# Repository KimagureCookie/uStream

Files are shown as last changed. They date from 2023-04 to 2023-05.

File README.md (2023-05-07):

### WIP (I'm working on the software side of things right now!)

A few weeks ago, I wanted to buy a hot air station for some smd rework. While I was searchig for one, I came across a lot of chinese hot air stations which seem to be dirt cheap and also resonably reliable. Howerver the problem is that, these seem to be outdated design and somewhat lack in saftey!
On the other hand the offerings from top players like JBC and Wellers seems to be out of reach for any hobbyist.

I guess these are enough excuses for making my own hot air station. Since I can't make the core components (The Heater and air pump units) I will be working on the controller unit. The heater and pumps can be purchased easily through any online repair parts sellers or even better if you could directly buy from chinese sites like aliexpress. 

I will try to add everything I have cooked so far in the coming days.

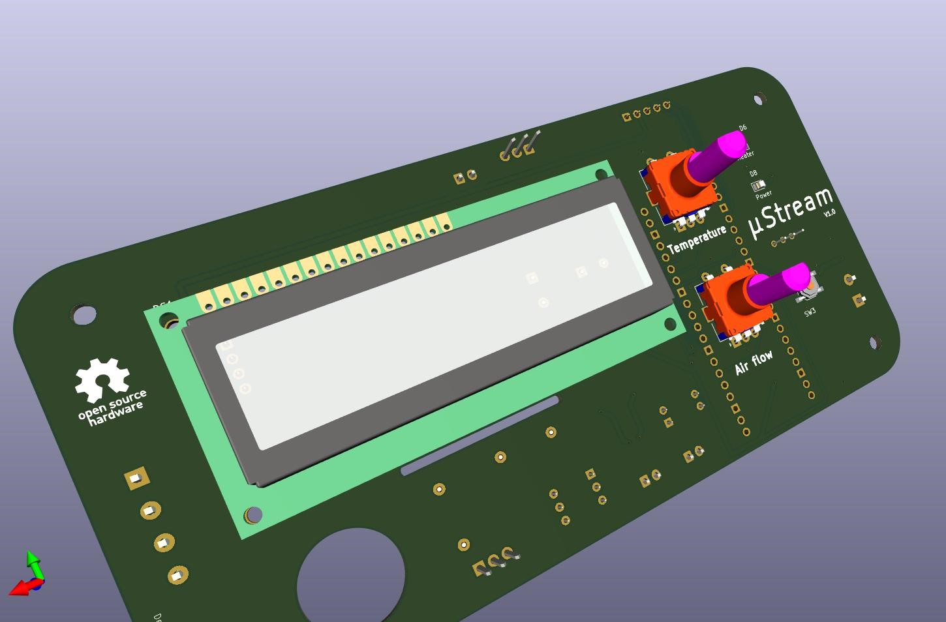
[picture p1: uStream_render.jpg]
micro_stream


Edit: As of now everthing on hardware is tested and corrected in schematics/PCB. The idea of implementing the thermocouple amplifier using an precision op-amp has to be scractched since, I can't figure out the problem with my current setup (glad I implemented the MAX6675 as a backup!).
Although I have run basic software tests, there is still more code to test thoroughly.

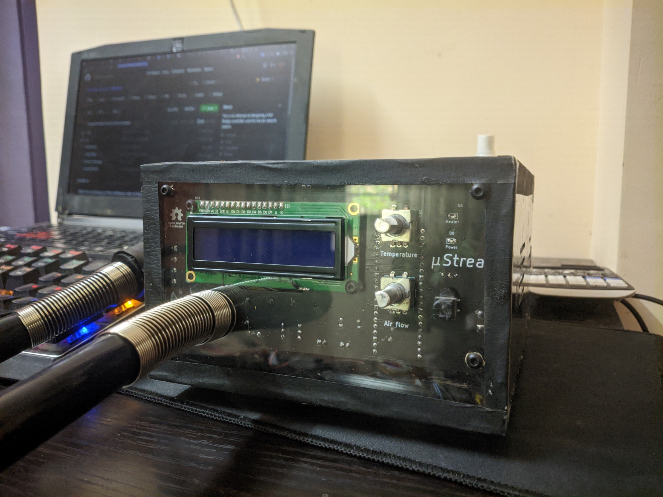
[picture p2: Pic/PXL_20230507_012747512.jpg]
p1


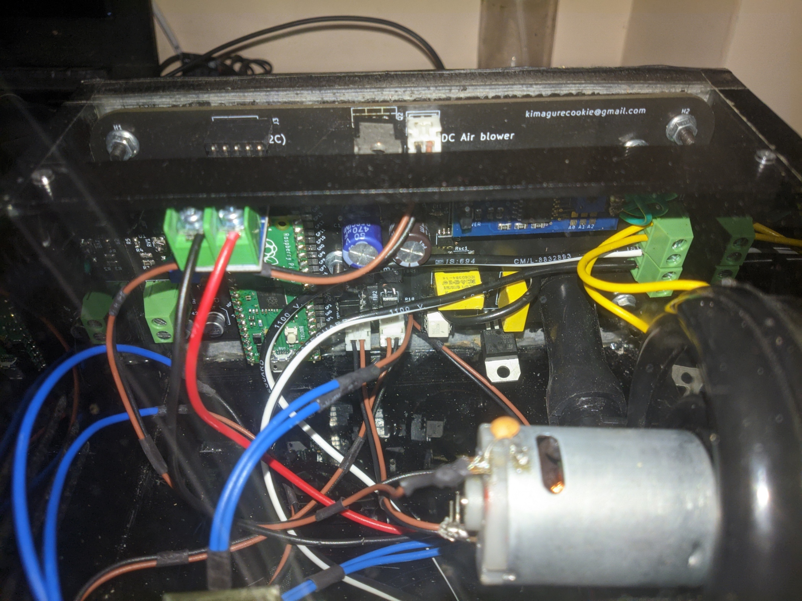
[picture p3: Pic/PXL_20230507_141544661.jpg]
p2


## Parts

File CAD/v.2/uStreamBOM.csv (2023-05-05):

Date: | 5/5/2023 1:10:16 PM
Tool: | Eeschema (6.0.10)
Generator: | C:\Program Files\KiCad\6.0\bin\scripting\plugins/bom_csv_grouped_by_value_with_fp.py
Component Count: | 72
Ref | Qnty | Value | Cmp name | Footprint | Description | Vendor
C1, C5, | 2 | 10u | C | Capacitor_SMD:C_0805_2012Metric_Pad1.18x1.45mm_HandSolder | Unpolarized capacitor
C2, | 1 | 480u | C_Polarized | Capacitor_THT:CP_Radial_D10.0mm_P5.00mm | Polarized capacitor
C3, C7, C11, | 3 | 10u | C_Polarized | Capacitor_SMD:CP_Elec_6.3x5.8 | Polarized capacitor
C4, C6, | 2 | 0.1u | C | Capacitor_SMD:C_0805_2012Metric_Pad1.18x1.45mm_HandSolder | Unpolarized capacitor
C8, | 1 | 220u | C_Polarized | Capacitor_THT:CP_Radial_D10.0mm_P5.00mm | Polarized capacitor
C9, | 1 | 50nf | C | Capacitor_THT:C_Rect_L13.0mm_W6.0mm_P10.00mm_FKS3_FKP3_MKS4 | Unpolarized capacitor
C10, | 1 | 10nf | C | Capacitor_THT:C_Rect_L13.0mm_W6.0mm_P10.00mm_FKS3_FKP3_MKS4 | Unpolarized capacitor
Ct1, | 1 | 260p | C | Capacitor_SMD:C_0805_2012Metric_Pad1.18x1.45mm_HandSolder | Unpolarized capacitor
D1, D4, D7, | 3 | 1N4148 | D | Diode_SMD:D_SOD-123 | Diode
D2, | 1 | 1N5819 | 1N5819 | Diode_SMD:D_SMA_Handsoldering | 40V 1A Schottky Barrier Rectifier Diode, DO-41
D3, | 1 | BZV55C4V7 | BZV55C4V7 | Diode_SMD:D_MiniMELF | 4.7V, 500mW, 5%, Zener diode, MiniMELF
D5, D6, | 2 | LED | LED | LED_SMD:LED_0805_2012Metric_Pad1.15x1.40mm_HandSolder | Light emitting diode
DS1, | 1 | WC1602A | WC1602A | Display:WC1602A | LCD 16x2 Alphanumeric , 8 bit parallel bus, 5V VDD
F1, | 1 | 1A | Fuse |  | Fuse
F2, | 1 | 3A | Fuse |  | Fuse
FBR1, | 1 | ABS10 | ABS10 | Diode_SMD:Diode_Bridge_Vishay_DFS | Miniature Glass Passivated Single-Phase Surface Mount Bridge Rectifiers, 700V Vrms, 0.8A If, ABS SMD package
FBR2, | 1 | RMB4S | RMB4S | Package_TO_SOT_SMD:TO-269AA | Miniature Glass Passivated Single-Phase Surface Mount Bridge Rectifiers, 280V Vrms, 0.5A If, TO-269AA
H1, H2, H3, H4, | 4 | MountingHole | MountingHole | MountingHole:MountingHole_3.2mm_M3 | Mounting Hole without connection
J1, | 1 | Transformer_In | Conn_01x02 | Connector_JST:JST_XH_B2B-XH-A_1x02_P2.50mm_Vertical | Generic connector, single row, 01x02, script generated (kicad-library-utils/schlib/autogen/connector/)
J2, | 1 | Thermocouple junction | Screw_Terminal_01x02 | TerminalBlock_Phoenix:TerminalBlock_Phoenix_MKDS-1,5-2-5.08_1x02_P5.08mm_Horizontal | Generic screw terminal, single row, 01x02, script generated (kicad-library-utils/schlib/autogen/connector/)
J3, | 1 | MAX6675 | Conn_01x05_Male | Connector_PinSocket_2.54mm:PinSocket_1x05_P2.54mm_Vertical | Generic connector, single row, 01x05, script generated (kicad-library-utils/schlib/autogen/connector/)
J4, | 1 | Mains+Heater | Screw_Terminal_01x04 | TerminalBlock_Phoenix:TerminalBlock_Phoenix_MKDS-1,5-4-5.08_1x04_P5.08mm_Horizontal | Generic screw terminal, single row, 01x04, script generated (kicad-library-utils/schlib/autogen/connector/)
J5, | 1 | Air Blower | Conn_01x02 | Connector_JST:JST_XH_B2B-XH-A_1x02_P2.50mm_Vertical | Generic connector, single row, 01x02, script generated (kicad-library-utils/schlib/autogen/connector/)
L1, | 1 | 68u | L | Inductor_SMD:L_Sunlord_SWPA80xxS | Inductor
Q1, | 1 | BTA16-600B | BTA16-600B | Package_TO_SOT_THT:TO-220-3_Vertical | 16A RMS, 600V Off-State Voltage, 50mA Sensitivity, Insulated, Triac, TO-220
Q2, | 1 | STP55NF06 | IRF540N | Package_TO_SOT_THT:TO-220-3_Vertical | 33A Id, 100V Vds, HEXFET N-Channel MOSFET, TO-220
R1, | 1 | 47k | R | Resistor_SMD:R_0805_2012Metric_Pad1.20x1.40mm_HandSolder | Resistor
R2, | 1 | 6.8k | R | Resistor_SMD:R_0805_2012Metric_Pad1.20x1.40mm_HandSolder | Resistor
R3, | 1 | 110 | R | Resistor_SMD:R_0805_2012Metric_Pad1.20x1.40mm_HandSolder | Resistor
R4, | 1 | 102k | R | Resistor_SMD:R_0805_2012Metric_Pad1.20x1.40mm_HandSolder | Resistor
R5, R16, | 2 | 51 | R | Resistor_SMD:R_0805_2012Metric_Pad1.20x1.40mm_HandSolder | Resistor
R6, R21, | 2 | 1k | R | Resistor_SMD:R_0805_2012Metric_Pad1.20x1.40mm_HandSolder | Resistor
R7, | 1 | 2k | R | Resistor_SMD:R_0805_2012Metric_Pad1.20x1.40mm_HandSolder | Resistor
R8, | 1 | 43k | R | Resistor_SMD:R_0805_2012Metric_Pad1.20x1.40mm_HandSolder | Resistor
R9, | 1 | 2.4k | R | Resistor_SMD:R_0805_2012Metric_Pad1.20x1.40mm_HandSolder | Resistor
R10, | 1 | 1.5k | R | Resistor_SMD:R_0805_2012Metric_Pad1.20x1.40mm_HandSolder | Resistor
R11, | 1 | 9.1k | R | Resistor_SMD:R_0805_2012Metric_Pad1.20x1.40mm_HandSolder | Resistor
R12, R13, R14, R15, R22, | 5 | 10k | R | Resistor_SMD:R_0805_2012Metric_Pad1.20x1.40mm_HandSolder | Resistor
R17, | 1 | 510 | R | Resistor_SMD:R_0805_2012Metric_Pad1.20x1.40mm_HandSolder | Resistor
R18, | 1 | 360 | R | Resistor_SMD:R_1206_3216Metric_Pad1.30x1.75mm_HandSolder | Resistor
R19, | 1 | 680 | R | Resistor_SMD:R_1206_3216Metric_Pad1.30x1.75mm_HandSolder | Resistor
R20, | 1 | 360 | R | Resistor_SMD:R_0805_2012Metric_Pad1.20x1.40mm_HandSolder | Resistor
R23, | 1 | 39 | R | Resistor_SMD:R_1206_3216Metric_Pad1.30x1.75mm_HandSolder | Resistor
Rsc1, | 1 | 0.3 | R | Resistor_SMD:R_2512_6332Metric_Pad1.40x3.35mm_HandSolder | Resistor
RV1, | 1 | 100 | R_Potentiometer | Potentiometer_SMD:Potentiometer_Bourns_TC33X_Vertical | Potentiometer
RV2, | 1 | 20k | R_Potentiometer | Potentiometer_THT:Potentiometer_Bourns_3296W_Vertical | Potentiometer
SW1, | 1 | Heater Encoder | RotaryEncoder_Switch | Rotary_Encoder:RotaryEncoder_Alps_EC11E-Switch_Vertical_H20mm | Rotary encoder, dual channel, incremental quadrate outputs, with switch
SW2, | 1 | Control for Air blower | RotaryEncoder_Switch | Rotary_Encoder:RotaryEncoder_Alps_EC11E-Switch_Vertical_H20mm | Rotary encoder, dual channel, incremental quadrate outputs, with switch
SW3, | 1 | SW_SPST | SW_SPST | Button_Switch_SMD:SW_SPST_TL3342 | Single Pole Single Throw (SPST) switch
SW_REED1, | 1 | SW_Reed | SW_Reed | Connector_JST:JST_XH_B2B-XH-A_1x02_P2.50mm_Vertical | reed switch
U1, | 1 | OP07 | OP07 | Package_SO:SOIC-8_3.9x4.9mm_P1.27mm | Single Ultra-Low Offset Voltage Operational Amplifier, DIP-8/SOIC-8
U2, | 1 | MC34063AD | MC34063AD | Package_SO:SOIC-8_3.9x4.9mm_P1.27mm | 1.5A, step-up/down/inverting switching regulator, 3-40V Vin, 100kHz, SO-8
U3, | 1 | PC817 | PC817 | Package_DIP:DIP-4_W7.62mm | DC Optocoupler, Vce 35V, CTR 50-300%, DIP-4
U4, | 1 | EA_T123X-I2C | EA_T123X-I2C | Connector_PinSocket_2.54mm:PinSocket_1x04_P2.54mm_Vertical | 3 Lines, 12 character alpha numeric LCD, transreflective STN and FSTN Gray, I2C, single or dual power
U5, | 1 | Pico | Pico | raspberry pi:RPi_Pico_SMD_TH
U6, | 1 | MOC3022M | MOC3022M | Package_DIP:DIP-6_W7.62mm | Random Phase Opto-Triac, Vdrm 400V, Ift 10mA, DIP6

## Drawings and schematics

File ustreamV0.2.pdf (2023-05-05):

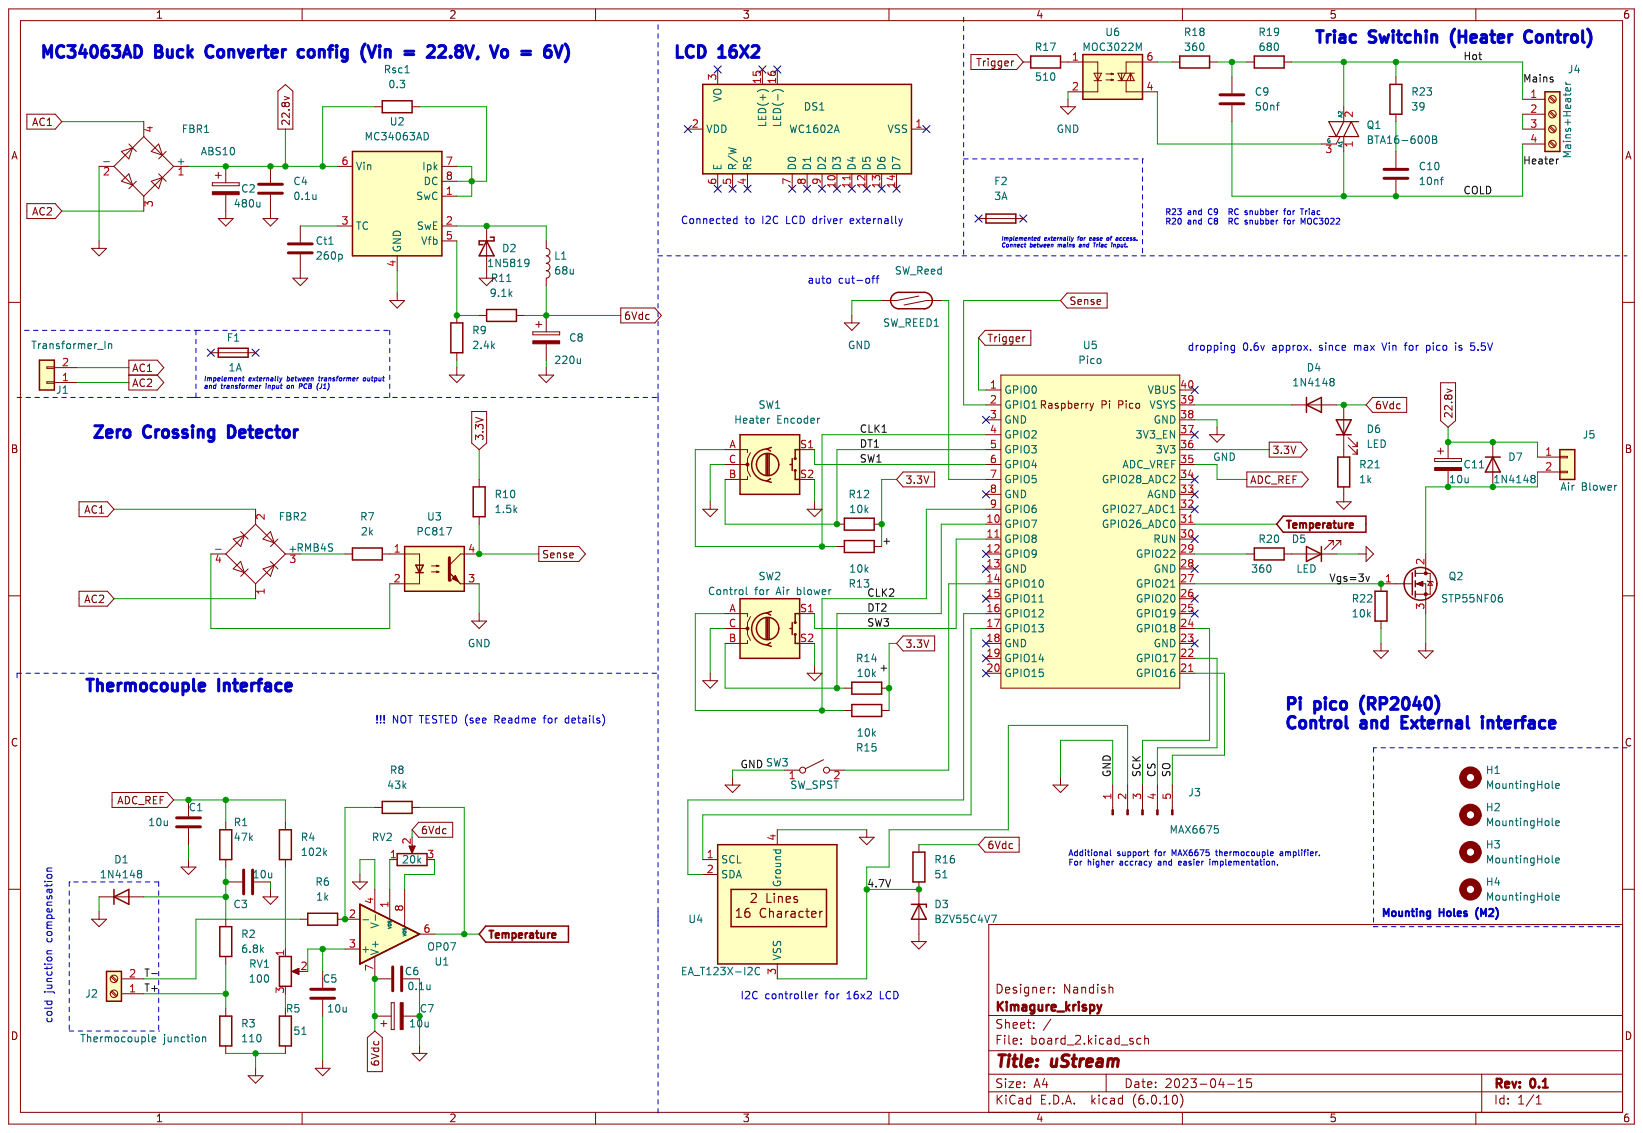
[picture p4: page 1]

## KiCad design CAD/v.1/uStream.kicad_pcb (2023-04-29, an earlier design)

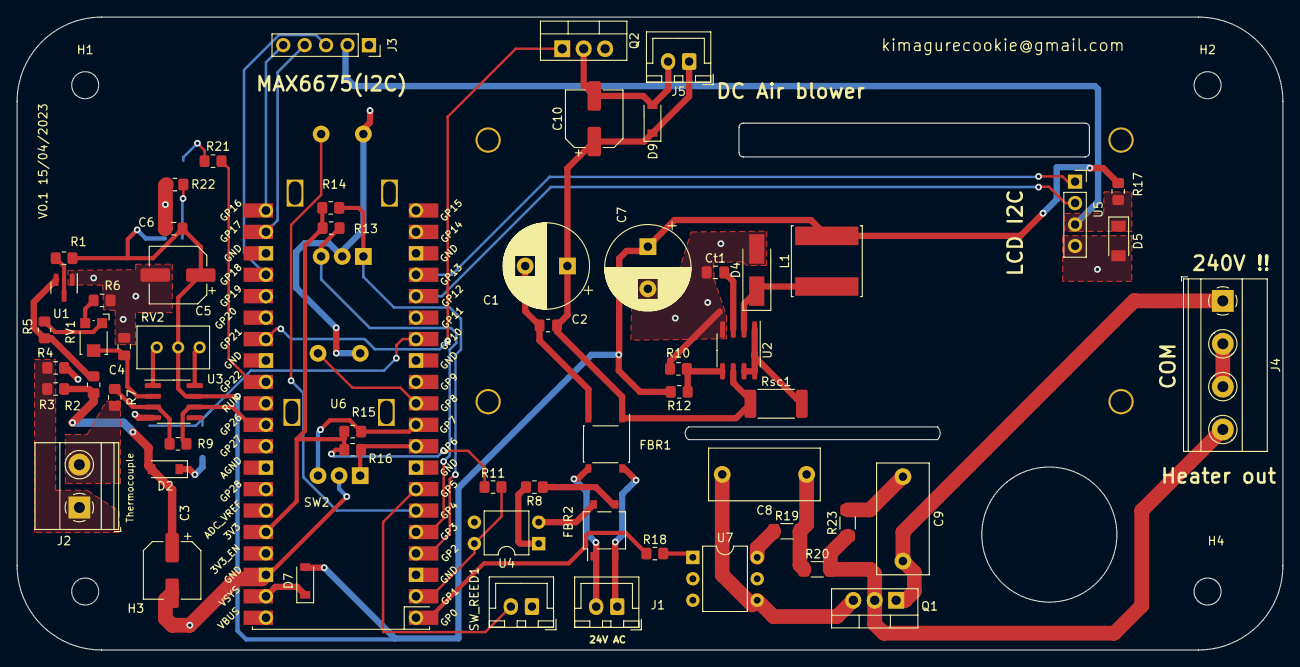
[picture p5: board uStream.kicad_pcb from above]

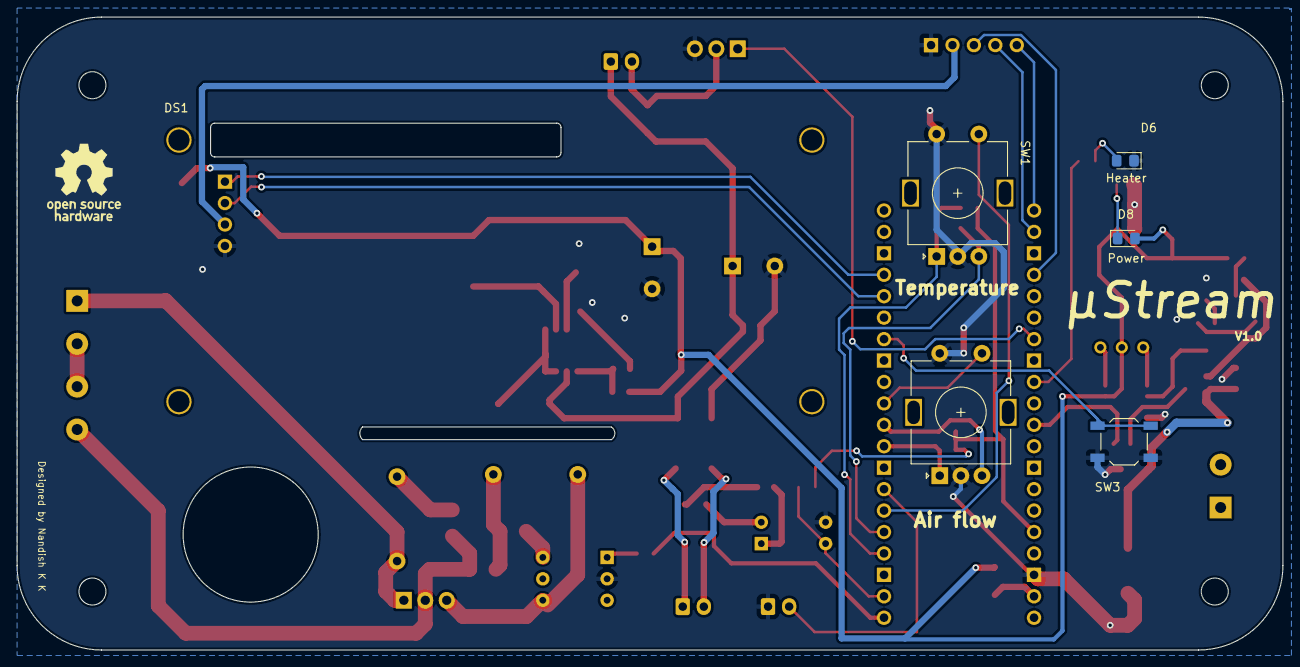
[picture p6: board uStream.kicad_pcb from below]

Board: 2 copper layers, 150.0 x 75.0 mm, 71 parts (7 on the bottom side), 55 nets.

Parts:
C1: 480u; CP_Radial_D10.0mm_P5.00mm
C2, C6: 0.1u; C_0805_2012Metric_Pad1.18x1.45mm_HandSolder
C3, C5, C10: 10u; CP_Elec_6.3x5.8
C4: 10u; C_0805_2012Metric_Pad1.18x1.45mm_HandSolder
C7: 220u; CP_Radial_D10.0mm_P5.00mm
C8: 50nf; C_Rect_L13.0mm_W6.0mm_P10.00mm_FKS3_FKP3_MKS4
C9: 10nf; C_Rect_L13.0mm_W6.0mm_P10.00mm_FKS3_FKP3_MKS4
Ct1: 260p; C_0805_2012Metric_Pad1.18x1.45mm_HandSolder
D2, D7, D9: 1N4148; D_SOD-123
D4: 1N5819; D_SMA_Handsoldering
D5: BZV55C4V7; D_MiniMELF
D6, D8: LED; LED_0805_2012Metric_Pad1.15x1.40mm_HandSolder
DS1: WC1602A
FBR1: ABS10; Diode_Bridge_Diotec_ABS
FBR2: RMB4S; TO-269AA
G: LOGO
H1, H2, H3, H4: MountingHole_3.2mm_M3
J1: Transformer_In; JST_XH_B2B-XH-A_1x02_P2.50mm_Vertical
J2: Thermocouple junction; TerminalBlock_Phoenix_MKDS-1,5-2-5.08_1x02_P5.08mm_Horizont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
J3: MAX6675; PinSocket_1x05_P2.54mm_Vertical
J4: Mains+Heater; TerminalBlock_Phoenix_MKDS-1,5-4-5.08_1x04_P5.08mm_Horizont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
J5: Air Blower; JST_XH_B2B-XH-A_1x02_P2.50mm_Vertical
L1: 68u; L_Sunlord_SWPA80xxS
Q1: BTA16-600B; TO-220-3_Vertical
Q2: STP55NF06; TO-220-3_Vertical
R1, R7, R22: 1k; R_0805_2012Metric_Pad1.20x1.40mm_HandSolder
R2: 47k; R_0805_2012Metric_Pad1.20x1.40mm_HandSolder
R3: 6.8k; R_0805_2012Metric_Pad1.20x1.40mm_HandSolder
R4: 110; R_0805_2012Metric_Pad1.20x1.40mm_HandSolder
R5: 102k; R_0805_2012Metric_Pad1.20x1.40mm_HandSolder
R6: 50; R_0805_2012Metric_Pad1.20x1.40mm_HandSolder
R8: 2k; R_0805_2012Metric_Pad1.20x1.40mm_HandSolder
R9: 43k; R_0805_2012Metric_Pad1.20x1.40mm_HandSolder
R10: 2.4k; R_0805_2012Metric_Pad1.20x1.40mm_HandSolder
R11: 1.5k; R_0805_2012Metric_Pad1.20x1.40mm_HandSolder
R12: 9.1k; R_0805_2012Metric_Pad1.20x1.40mm_HandSolder
R13, R14, R15, R16: 10k; R_0805_2012Metric_Pad1.20x1.40mm_HandSolder
R17: 51; R_0805_2012Metric_Pad1.20x1.40mm_HandSolder
R18: 510; R_0805_2012Metric_Pad1.20x1.40mm_HandSolder
R19: 360; R_1206_3216Metric_Pad1.30x1.75mm_HandSolder
R20: 680; R_1206_3216Metric_Pad1.30x1.75mm_HandSolder
R21: 360; R_0805_2012Metric_Pad1.20x1.40mm_HandSolder
R23: 39; R_1206_3216Metric_Pad1.30x1.75mm_HandSolder
RV1: 100; Potentiometer_Bourns_TC33X_Vertical
RV2: 20k; Potentiometer_Bourns_3296W_Vertical
Rsc1: 0.3; R_2512_6332Metric_Pad1.40x3.35mm_HandSolder
SW1: Heater Encoder; RotaryEncoder_Alps_EC11E-Switch_Vertical_H20mm
SW2: Control for Air blower; RotaryEncoder_Alps_EC11E-Switch_Vertical_H20mm
SW3: SW_SPST; SW_SPST_TL3342
SW_REED1: SW_Reed; JST_XH_B2B-XH-A_1x02_P2.50mm_Vertical
U1: TL431DBZ; SOT-23
U2: MC34063AD; SOIC-8_3.9x4.9mm_P1.27mm
U3: OP07; SOIC-8_3.9x4.9mm_P1.27mm
U4: PC817; DIP-4_W7.62mm
U5: EA_T123X-I2C; PinSocket_1x04_P2.54mm_Vertical
U6: Pico; RPi_Pico_SMD_TH
U7: MOC3022M; DIP-6_W7.62mm

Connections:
3.3V: R11.1, R13.2, R14.2, R15.2, R16.2, U6.36 (3V3)
6Vdc: C5.1, C6.2, C7.1, D7.2 (A), D8.2 (A), L1.2, R1.2, R12.2, R17.1, RV2.2, U3.7 (V+)
22.8v: C1.1, C2.2, C10.1, D9.1 (K), FBR1.1 (+), J5.1, Rsc1.1, U2.6 (Vin)
/4.7V: D5.1 (K), J3.2, R17.2, U5.3 (VSS)
/CLK1: R14.1, SW1.A, U6.4 (GPIO2)
/CLK2: R16.1, SW2.A, U6.9 (GPIO6)
/COLD: C9.2, J4.1, Q1.1 (A1)
/CS: J3.4, U6.22 (GPIO17)
/DT1: R13.1, SW1.B, U6.5 (GPIO3)
/DT2: R15.1, SW2.B, U6.10 (GPIO7)
/Hot: J4.4, Q1.2 (A2), R20.2, R23.1
/SCK: J3.3, U6.24 (GPIO18)
/SO: J3.5, U6.21 (GPIO16)
/SW1: SW1.S1, U6.6 (GPIO4)
/SW3: SW2.S1, U6.11 (GPIO8)
/T+: J2.1, R3.1, R4.2
/T-: J2.2, R7.2
/Vgs=3v: Q2.1 (G), U6.27 (GPIO21)
AC1: FBR1.4, FBR2.2, J1.1
AC2: FBR1.3, FBR2.1, J1.2
GND: C1.2, C2.1, C3.2, C4.2, C5.2, C6.1, C7.2, Ct1.1, D2.1 (K), D4.2 (A), D5.2 (A), D6.1 (K), FBR1.2 (-), J3.1, Q2.3 (S), R4.1, R6.1, R10.2, R22.2, SW1.C, SW1.S2, SW2.C, SW2.S2, SW3.1 (A), SW_REED1.1, U1.1 (K), U2.4 (GND), U3.4 (V-), U4.3, U5.4 (Ground), U6.38 (GND), U7.2
unnamed: C3.1, D2.2 (A), R2.1, R3.2
unnamed: C4.1, RV1.2, U3.2 (-)
unnamed: C8.1, R19.2, R20.1
unnamed: C8.2, Q1.3 (G), U7.4
unnamed: C9.1, R23.2
unnamed: C10.2, D9.2 (A), J5.2, Q2.2 (D)
unnamed: Ct1.2, U2.3 (TC)
unnamed: D4.1 (K), L1.1, U2.2 (SwE)
unnamed: D6.2 (A), R21.2
unnamed: D7.1 (K), U6.39 (VSYS)
unnamed: D8.1 (K), R22.1
unnamed: FBR2.3 (+), R8.1
unnamed: FBR2.4 (-), U4.2
unnamed: J4.2, J4.3
unnamed: R1.1, U1.3 (A)
unnamed: R2.2, R5.1, U1.2 (REF)
unnamed: R5.2, RV1.1
unnamed: R6.2, RV1.3
unnamed: R7.1, R9.2, U3.3 (+)
unnamed: R8.2, U4.1
unnamed: R10.1, R12.1, U2.5 (Vfb)
unnamed: R18.2, U7.1
unnamed: R19.1, U7.6
unnamed: R21.1, U6.29 (GPIO22)
unnamed: RV2.1, U3.8 (VOS)
unnamed: RV2.3, U3.1 (VOS)
unnamed: Rsc1.2, U2.1 (SwC), U2.7 (Ipk), U2.8 (DC)
unnamed: SW3.2 (B), U6.14 (GPIO10)
unnamed: SW_REED1.2, U6.7 (GPIO5)
unnamed: U5.1 (SCL), U6.17 (GPIO13)
unnamed: U5.2 (SDA), U6.16 (GPIO12)
Sense: R11.2, U4.4, U6.2 (GPIO1)
Temperature: R9.1, U3.6, U6.31 (GPIO26_ADC0)
Trigger: R18.1, U6.1 (GPIO0)

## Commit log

2023-04-29 CAD files added
    [uStream.kicad_pcb, uStream.kicad_sch, uStream_BOM.csv]
2023-05-06 schematic and pcb updated
    [uStream.kicad_pcb_v2.kicad_pcb, uStream.kicad_sch_v.kicad_sch]
